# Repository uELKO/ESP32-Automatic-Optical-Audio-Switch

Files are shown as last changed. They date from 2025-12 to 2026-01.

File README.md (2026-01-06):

# Automatic Optical Audio Switch (ESP32)

{8CCD83B7-7E51-4EB5-BC00-117256F870E5}

Automatic switching between **two TOSLINK / SPDIF inputs** to **one output**
based on signal activity detection with an ESP32C3.

---

## Features
- 2× optical input → 1× optical output
- Automatic source selection (A/B)
- Signal detection via frequency measurement
- Configurable thresholds and timing
- Anti-flicker logic
- ESPHome firmware
- Web UI and Home Assistant integration
- No SPDIF decoding or audio processing
- USB-C powered
- 3D-printed enclosure

---

## Concept
Each optical input is converted into a digital pulse stream.
The ESP32 measures the divided SPDIF clock frequency and switches the output
to the active (playing) channel.

ESP32-Optical-Audio-Switch-System-Diagram drawio

> [!NOTE]
> The actual audio path is switched purely in hardware. The ESP32 only controls the selection logic and does not touch the audio data stream itself.

---

## Build
1. Assemble PCB according to the KiCad project
2. Flash ESPHome/OTA firmware
3. Use Web UI or Home Assistant for configuration
4. Connect device to optical audio setup

---

## Documentation
Detailed explanations, diagrams and project logs are available on: **[Project page – Hackaday.io](https://hackaday.io/project/204791-automatic-optical-audio-switch-esp32)**

---

## PCBs
If you want to buy a bare or assembled PCB of this project, use this link to support me, thanks!

https://www.pcbway.com/project/shareproject/Automatic_Optical_Audio_Switch_ESP32_13712e76.html

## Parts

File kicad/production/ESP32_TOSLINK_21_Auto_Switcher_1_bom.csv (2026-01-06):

Designator | Footprint | Quantity | Value | LCSC Part #
C1, C2, C3, C4, C5, C6 | 0805 | 6 | 1uF
C7, C8 | 0805 | 2 | 10uF
D2, D3 | LED_Kingbright_APA1606_1.6x0.6mm_Horizontal | 2 | LED
IC1 | SOP65P210X110-6N | 1 | 74LVC1G157GW,125
J1, J2 | ORJ-8 | 2 | FC684208R
L1 | 0805 | 1 | 100R
R1, R2, R3, R4, R5 | 0805 | 5 | 50R
R6 | 0805 | 1 | 330R
TP1, TP2, TP3, TP4, TP5 | TestPoint_Pad_D1.0mm | 5 | TestPoint
U1, U2 | SOT-353_SC-70-5 | 2 | 74AHC1G4212
U3 | MODULE_ESP32-C3-ZERO | 1 | ESP32-C3-ZERO
U4 | FCR684208T_R | 1 | FCR684208T
U5 | SOT-23-5 | 1 | AP2127K-3.3

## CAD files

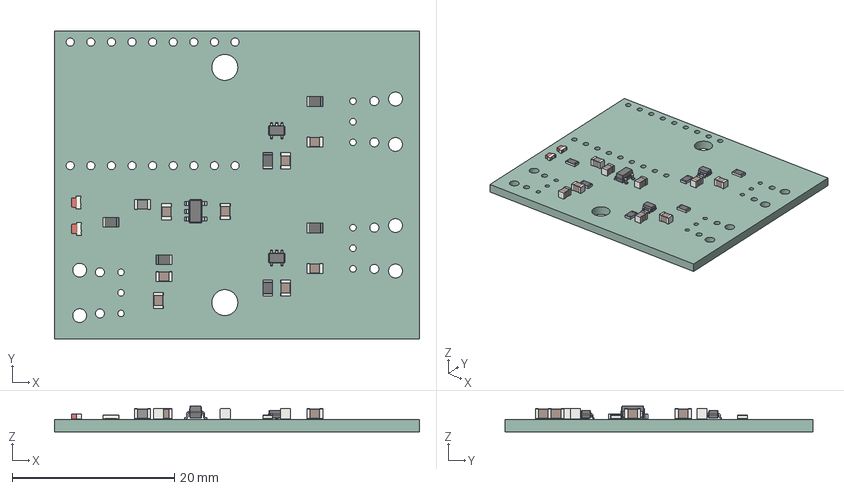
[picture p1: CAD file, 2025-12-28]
kicad/ESP32-Automatic-Optical-Audio-Switch.step
45.0 x 38.0 x 3.15 mm
C_0805_2012Metric x 8
R_0805_2012Metric x 6
SOT-23-5
SOT-353_SC-70-5 x 2
L_0805_2012Metric
LED_Kingbright_APA1606_1.6x0.6mm_Horizontal x 2
ESP32-Toslink-Switcher_PCB

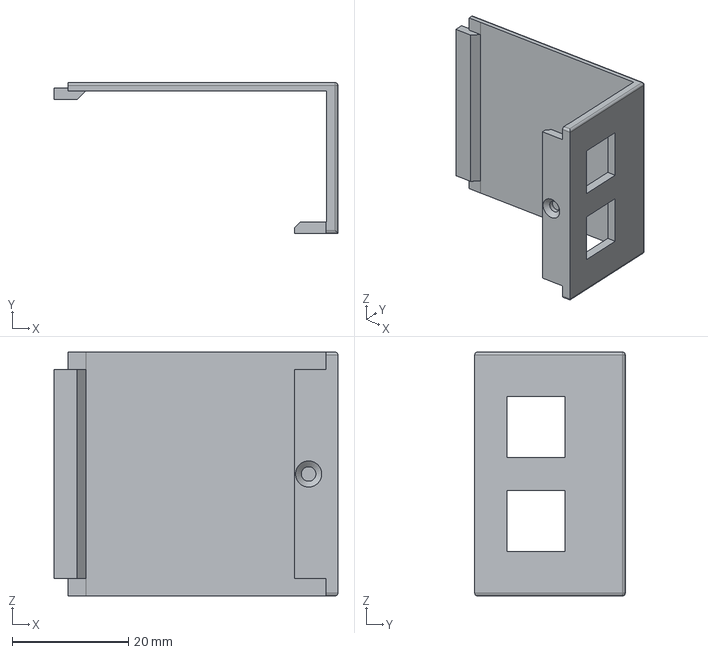
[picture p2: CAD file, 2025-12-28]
mechanics/Top.step
48.9 x 26.0 x 42.0 mm

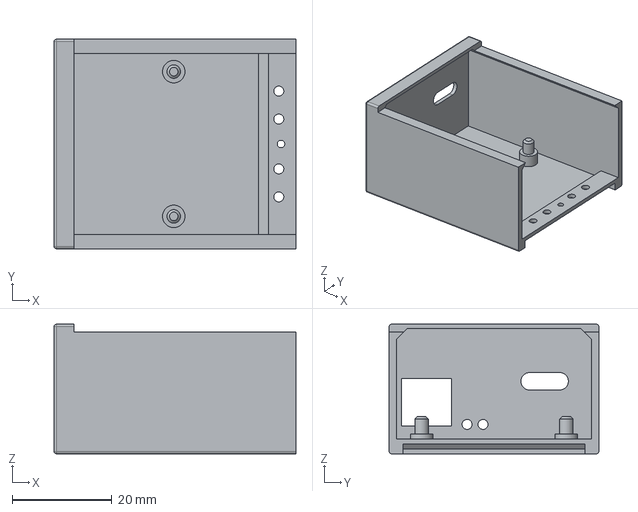
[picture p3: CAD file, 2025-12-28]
mechanics/Bottom.step
48.5 x 42.0 x 26.0 mm

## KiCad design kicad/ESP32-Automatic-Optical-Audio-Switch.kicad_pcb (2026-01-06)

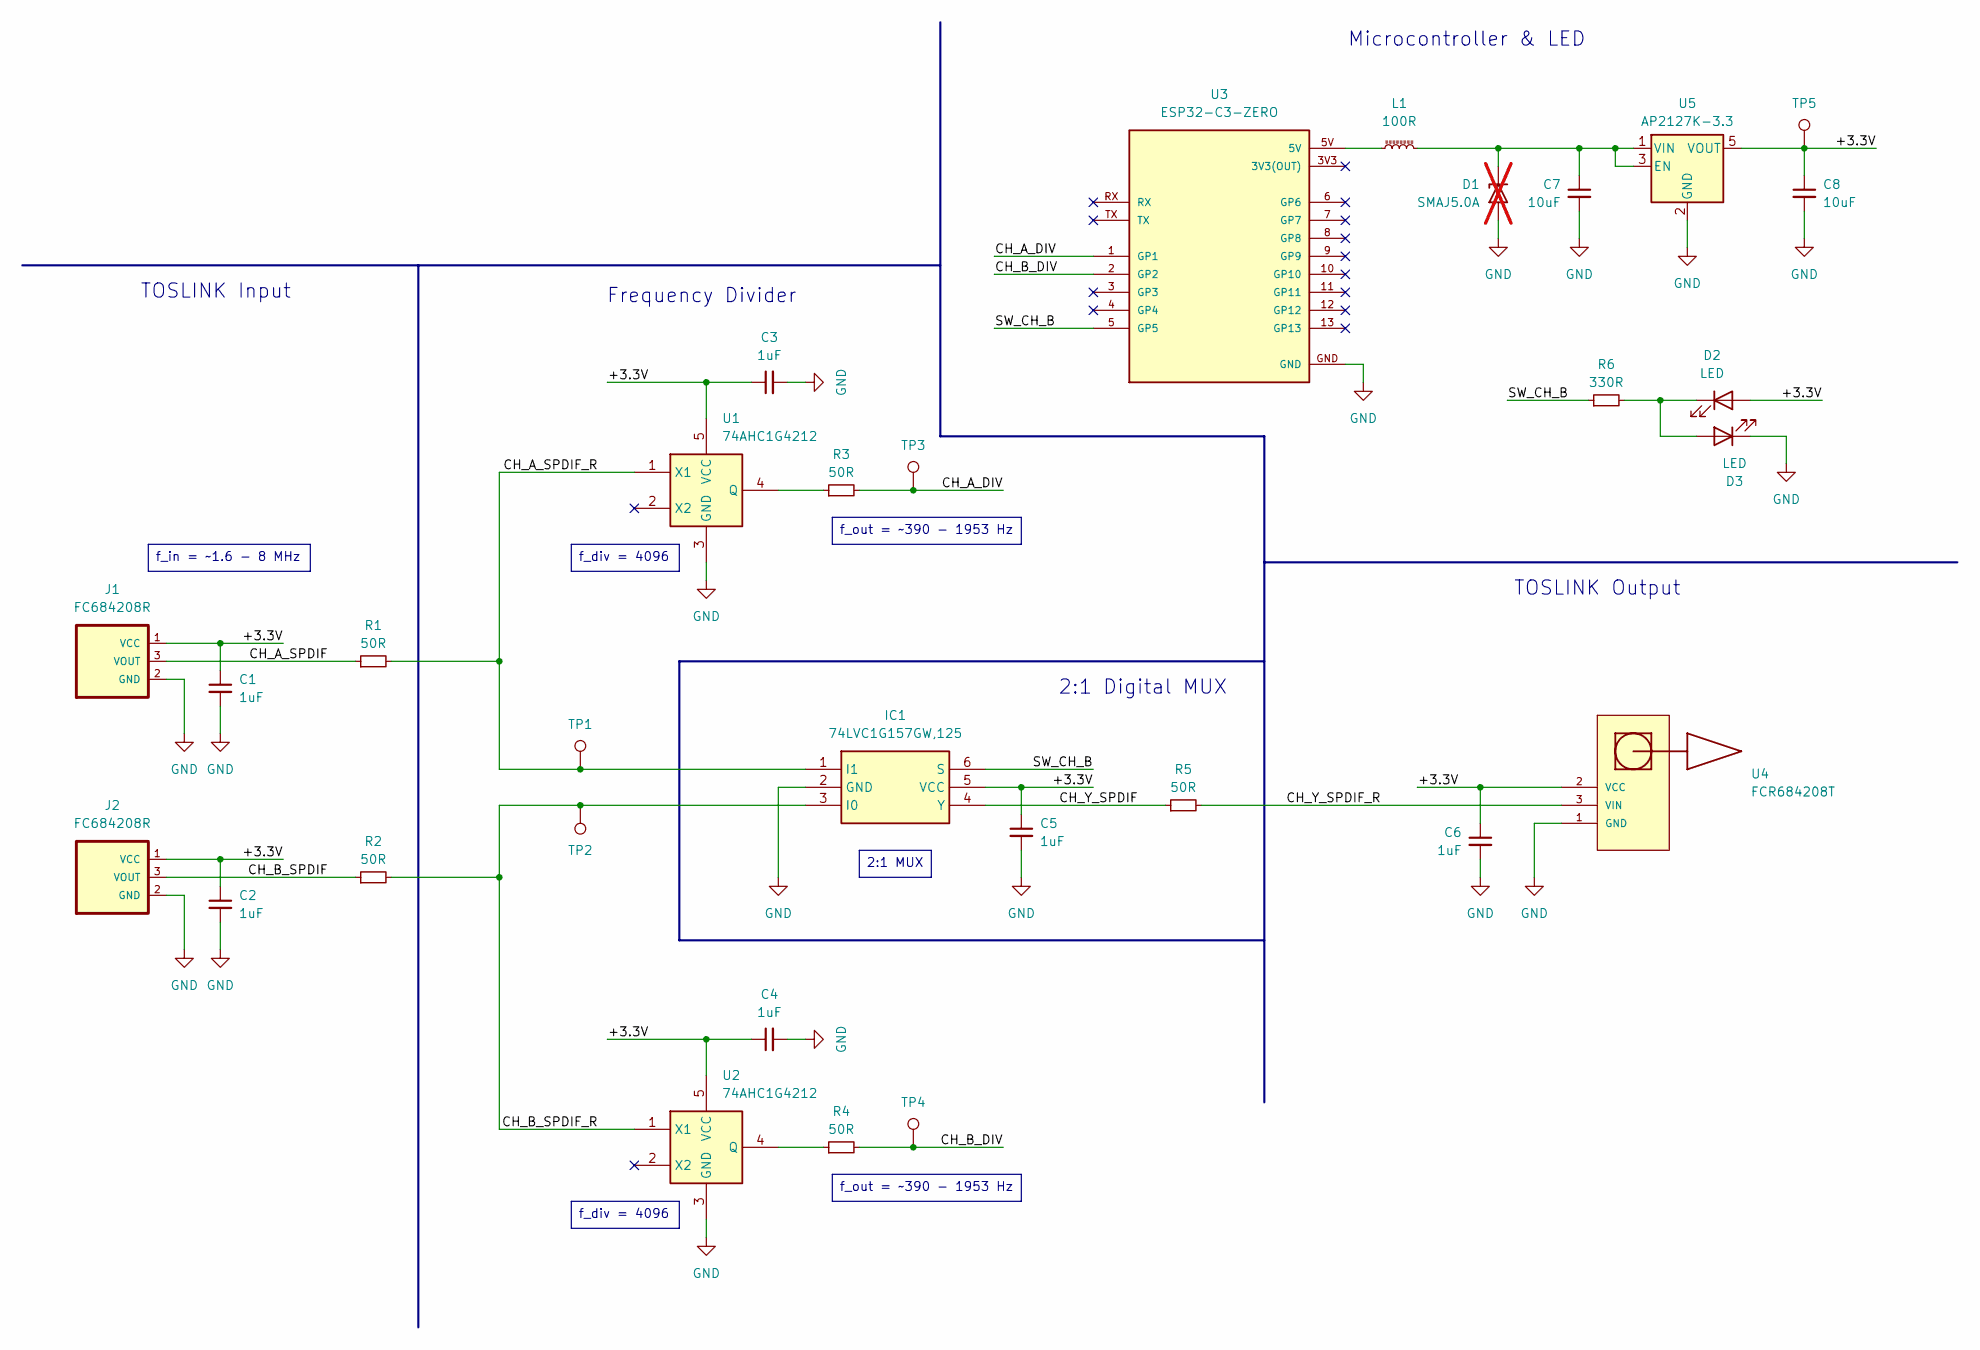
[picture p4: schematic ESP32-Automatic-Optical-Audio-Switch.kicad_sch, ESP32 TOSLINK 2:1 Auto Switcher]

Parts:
C1, C2, C3, C4, C5, C6: 1uF; C_0805_2012Metric
C7, C8: 10uF; C_0805_2012Metric
D1: SMAJ5.0A; D_SMA; not fitted
D2, D3: LED; LED_Kingbright_APA1606_1.6x0.6mm_Horizontal
IC1: 74LVC1G157GW,125; SOP65P210X110-6N; Mouser Part Number 771-74LVC1G157GW-G
J1, J2: FC684208R; ORJ-8
L1: 100R; L_0805_2012Metric
R1, R2, R3, R4, R5: 50R; R_0805_2012Metric
R6: 330R; R_0805_2012Metric
TP1, TP2, TP3, TP4, TP5: TestPoint; TestPoint_Pad_D1.0mm
U1, U2: 74AHC1G4212; SOT-353_SC-70-5
U3: ESP32-C3-ZERO; MODULE_ESP32-C3-ZERO; PARTREV NA
U4: FCR684208T; FCR684208T_R
U5: AP2127K-3.3; SOT-23-5

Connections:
/+3.3V: C1.1, C2.1, C3.1, C4.1, C5.1, C6.1, C8.1, D2.2 (A), IC1.5 (VCC), J1.1 (VCC), J2.1 (VCC), TP5.1, U1.5 (VCC), U2.5 (VCC), U4.2 (VCC), U5.5 (VOUT)
/CH_A_DIV: R3.2, TP3.1, U3.1 (GP1)
/CH_A_SPDIF: J1.3 (VOUT), R1.1
/CH_A_SPDIF_R: IC1.1 (I1), R1.2, TP1.1, U1.1 (X1)
/CH_B_DIV: R4.2, TP4.1, U3.2 (GP2)
/CH_B_SPDIF: J2.3 (VOUT), R2.1
/CH_B_SPDIF_R: IC1.3 (I0), R2.2, TP2.1, U2.1 (X1)
/CH_Y_SPDIF: IC1.4 (Y), R5.1
/CH_Y_SPDIF_R: R5.2, U4.3 (VIN)
/SW_CH_B: IC1.6 (S), R6.1, U3.5 (GP5)
GND: C1.2, C2.2, C3.2, C4.2, C5.2, C6.2, C7.2, C8.2, D1.2 (A2), D3.1 (K), IC1.2 (GND), J1.2 (GND), J2.2 (GND), U1.3 (GND), U2.3 (GND), U3.GND, U4.1 (GND), U4.MP1 (GND), U4.MP2 (GND), U5.2 (GND)
unnamed: D2.1 (K), D3.2 (A), R6.2
unnamed: L1.1, U3.5V
unnamed: R3.1, U1.4 (Q)
unnamed: R4.1, U2.4 (Q)
unnamed: C7.1, D1.1 (A1), L1.2, U5.1 (VIN), U5.3 (EN)

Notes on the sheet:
2:1 Digital MUX
Frequency Divider
TOSLINK Output
Microcontroller & LED
TOSLINK Input
f_div = 4096
f_out = ~390 - 1953 Hz
2:1 MUX
f_in = ~1.6 - 8 MHz

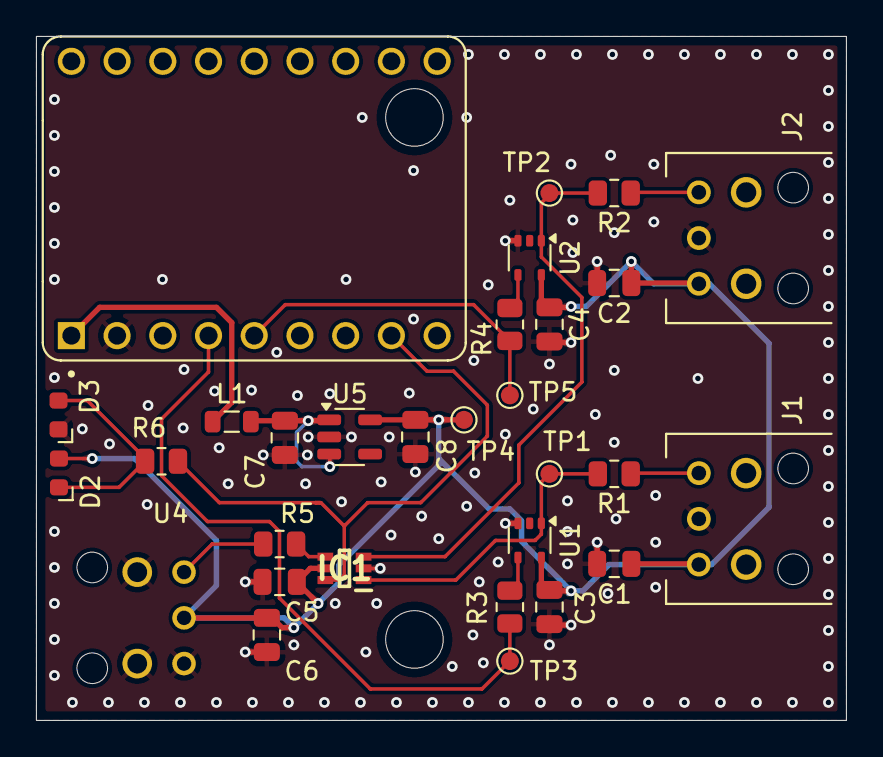
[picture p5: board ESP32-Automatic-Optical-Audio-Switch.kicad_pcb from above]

Board: 2 copper layers, 45.0 x 38.0 mm, 30 parts (0 on the bottom side), 16 nets.

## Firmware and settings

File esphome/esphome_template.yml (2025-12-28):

esphome:
  name: esphome-web-2e51ac
  friendly_name: ESP32C3-Toslink-Switch
  min_version: 2025.11.0
  name_add_mac_suffix: false

esp32:
  board: esp32-c3-devkitm-1
  variant: ESP32C3
  framework:
    type: arduino

# Enable logging
logger:

# Enable Home Assistant API
api:

# Allow Over-The-Air updates
ota:
- platform: esphome

wifi:
  ssid: !secret wifi_ssid
  password: !secret wifi_password

web_server:
  port: 80


switch:
  - platform: gpio
    id: switch_ab
    pin:
      number: 4
      mode:
        output: true
    name: "Switch CH A/B"

number:
  - platform: template
    name: "Frequency Threshold CH A"
    id: freq_threshold_ch_a
    optimistic: true
    min_value: 100
    max_value: 2000
    step: 25
    initial_value: 100
    restore_value: true
    mode: box

  - platform: template
    name: "Frequency Threshold CH B"
    id: freq_threshold_ch_b
    optimistic: true
    min_value: 100
    max_value: 2000
    step: 25
    initial_value: 100
    restore_value: true
    mode: box

  - platform: template
    name: "Switching Time CH A"
    id: switching_time_ch_a
    optimistic: true
    min_value: 500
    max_value: 4000
    step: 500
    initial_value: 500
    restore_value: true
    mode: box

  - platform: template
    name: "Switching Time CH B"
    id: switching_time_ch_b
    optimistic: true
    min_value: 500
    max_value: 4000
    step: 500
    initial_value: 500
    restore_value: true
    mode: box

sensor:
  - platform: pulse_counter
    id: pulse_counter_a
    pin:
      number: 0
      mode:
        input: true
        pulldown: true
    name: "Pulse Counter CH A"
    unit_of_measurement: "Hz"
    update_interval: 100 ms
    filters:
      - multiply: 0.01666667
      - round: 0


  - platform: pulse_counter
    id: pulse_counter_b
    pin:
      number: 1
      mode:
        input: true
        pulldown: true
    name: "Pulse Counter CH B"
    unit_of_measurement: "Hz"
    update_interval: 100 ms
    filters:
      - multiply: 0.01666667
      - round: 0


globals:
  # Startzeitpunkte (ms), 0 = nicht aktiv
  - id: a_start_ms
    type: uint32_t
    restore_value: no
    initial_value: '0'
  - id: b_start_ms
    type: uint32_t
    restore_value: no
    initial_value: '0'

  # damit nicht dauernd neu getriggert wird, solange Signal oben bleibt
  - id: a_armed
    type: bool
    restore_value: no
    initial_value: 'true'
  - id: b_armed
    type: bool
    restore_value: no
    initial_value: 'true'

interval:
  - interval: 200ms
    then:
      - lambda: |-
          const float fa = id(pulse_counter_a).state;
          const float fb = id(pulse_counter_b).state;

          const float tha = id(freq_threshold_ch_a).state;
          const float thb = id(freq_threshold_ch_b).state;

          const uint32_t ta = (uint32_t) id(switching_time_ch_a).state;
          const uint32_t tb = (uint32_t) id(switching_time_ch_b).state;

          const uint32_t now = millis();

          // --- Channel A: wenn fa > tha für ta ms => Switch AUS
          if (fa > tha) {
            if (id(a_armed)) {
              if (id(a_start_ms) == 0) id(a_start_ms) = now;
              if ((uint32_t)(now - id(a_start_ms)) >= ta) {
                id(switch_ab).turn_on();
                id(a_armed) = false;   // erst wieder aktivieren, wenn fa wieder <= tha war
                id(a_start_ms) = 0;
              }
            }
          } else {
            id(a_start_ms) = 0;
            id(a_armed) = true;        // wieder "armed", sobald wieder unter Schwellwert
          }

          // --- Channel B: wenn fb > thb für tb ms => Switch AN
          if (fb > thb) {
            if (id(b_armed)) {
              if (id(b_start_ms) == 0) id(b_start_ms) = now;
              if ((uint32_t)(now - id(b_start_ms)) >= tb) {
                id(switch_ab).turn_off();
                id(b_armed) = false;
                id(b_start_ms) = 0;
              }
            }
          } else {
            id(b_start_ms) = 0;
            id(b_armed) = true;
          }

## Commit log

2025-12-28 Add ESP32 optical audio switch KiCad and STEP files
    Initial commit of the ESP32-Automatic-Optical-Audio-Switch project, including KiCad PCB, schematic, project, and related files, as well as mechanical STEP models for enclosure parts.
    [Bottom.step, ESP32-Automatic-Optical-Audio-Switch.kicad_pcb, ESP32-Automatic-Optical-Audio-Switch.kicad_sch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]
2025-12-28 moved directory
    [ESP32-Automatic-Optical-Audio-Switch.kicad_pcb, ESP32-Automatic-Optical-Audio-Switch.kicad_sch, ESP32-Automatic-Optical-Audio-Switch.step]
2026-01-02 Add system diagram and update PCB for ESP32 switch
    Added a Draw.io system diagram for the ESP32 Optical Audio Switch. Updated the KiCad PCB and schematic files to reference the correct sheet file and replaced a capacitor footprint with the ESP32-C3-ZERO module footprint. Also updated .gitignore to exclude temporary Draw.io files.
    [ESP32-Automatic-Optical-Audio-Switch.kicad_pcb, ESP32-Automatic-Optical-Audio-Switch.kicad_sch]
2026-01-02 Revise README for Automatic Optical Audio Switch
    Updated project overview and features for clarity and conciseness. Added build instructions and improved formatting.
2026-01-06 Add PCB purchasing information to README
    Added section about purchasing PCBs for the project.
2026-01-06 Added production files
    [ESP32-Automatic-Optical-Audio-Switch.kicad_pcb, ESP32_TOSLINK_21_Auto_Switcher_1_bom.csv, ESP32_TOSLINK_21_Auto_Switcher_1_designators.csv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]
